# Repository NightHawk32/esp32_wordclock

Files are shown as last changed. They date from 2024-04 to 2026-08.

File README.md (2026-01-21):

# ESP32 WordClock - WiFi Setup Guide

This WordClock project is built around the **Ikea Sannahed 35x35cm picture frame**, transforming it into an elegant word-based time display with integrated sensors and web control.

## 📶 WiFi Setup

The WordClock features an automatic WiFi configuration system with two modes of operation:

### Initial Setup (Access Point Mode)

When the WordClock is powered on for the first time or cannot connect to a saved WiFi network, it automatically enters **Access Point (AP) Mode**:

1. **Connect to the WordClock's WiFi network:**
   - Network Name (SSID): `WordClock-Setup`
   - Password: `wordclock123`

2. **Access the configuration interface:**
   - Open your web browser and navigate to: `http://192.168.4.1`
   - You should see a yellow banner indicating "Access Point Mode"

3. **Configure your WiFi:**
   - Enter your home WiFi network name (SSID)
   - Enter your WiFi password
   - Click "Connect to WiFi"
   - The WordClock will save the settings and restart

4. **Reconnect to your home network:**
   - After restart, the WordClock will connect to your home WiFi
   - You can now disconnect from the `WordClock-Setup` network and reconnect to your home WiFi

### Normal Operation (Station Mode)

Once configured, the WordClock connects to your home WiFi network automatically. You can access the web interface in two ways:

#### Option 1: Using mDNS hostname (Recommended)
```
http://wordclock.local
```
This works on most devices without needing to know the IP address. The mDNS (Multicast DNS) service makes the WordClock discoverable on your local network.

> **Note:** mDNS may not work on all Android devices or older Windows versions. If `wordclock.local` doesn't work, use the IP address method below.

#### Option 2: Using IP Address
1. Check your router's DHCP client list to find the WordClock's IP address
2. Alternatively, connect via serial monitor (115200 baud) to see the IP address printed during startup
3. Navigate to: `http://[IP_ADDRESS]` (e.g., `http://192.168.1.100`)

## 🌐 Web Interface Features

Once connected, the web interface allows you to:

- **Display Mode:** Switch between word clock and digital clock modes
- **LED Color Control:** Adjust RGBW color values with preset options
- **Timezone Configuration:** Set your local timezone for accurate time display
- **Sensor Monitoring:** View real-time temperature, humidity, pressure, and brightness data
- **WiFi Reconfiguration:** Change WiFi settings if needed
- **Firmware Updates:** Update firmware over WiFi without USB cable (see OTA section below)

## 🔄 Over-The-Air (OTA) Firmware Updates

The WordClock supports wireless firmware updates, eliminating the need for USB cable after initial setup.

### Web-Based OTA Update (Recommended)

1. **Access the update page:**
   - Open http://wordclock.local
   - Click the "🔄 Go to Firmware Update Page" button
   - Or directly visit: http://wordclock.local/update

2. **Upload new firmware:**
   - Select the firmware file (`.bin`)
   - Click "Update"
   - Wait for the progress bar to complete
   - Device will automatically reboot

### PlatformIO Targets

You can also use PlatformIO to upload firmware over WiFi using the following target: OTA, which uses ArduinoOTA.
And uploads the firmware to the device over the network.
For the first upload you need to upload via the USB target to set up the WiFi connection.

### Windows Firewall / Defender Note

If OTA updates fail or timeout:
- **Windows Defender Firewall** may block OTA connections on port 3232
- **Solution:** Temporarily disable firewall or add exception for Python/PlatformIO
- **Alternative:** Use the web-based OTA method which uses standard HTTP port 80

## 🛠️ Hardware

This project is designed to fit perfectly in the **Ikea Sannahed 35x35cm picture frame**, providing a clean and modern aesthetic for your word clock display.

## 📝 Additional Configuration

After WiFi setup, you can configure:
- **Timezone:** Select from common timezones or use custom POSIX timezone strings
- **Display Colors:** Full RGBW control for customized appearance
- **Display Mode:** Choose between word-based or digital time display

The WordClock automatically syncs time via NTP (Network Time Protocol) when connected to WiFi, ensuring accurate timekeeping.

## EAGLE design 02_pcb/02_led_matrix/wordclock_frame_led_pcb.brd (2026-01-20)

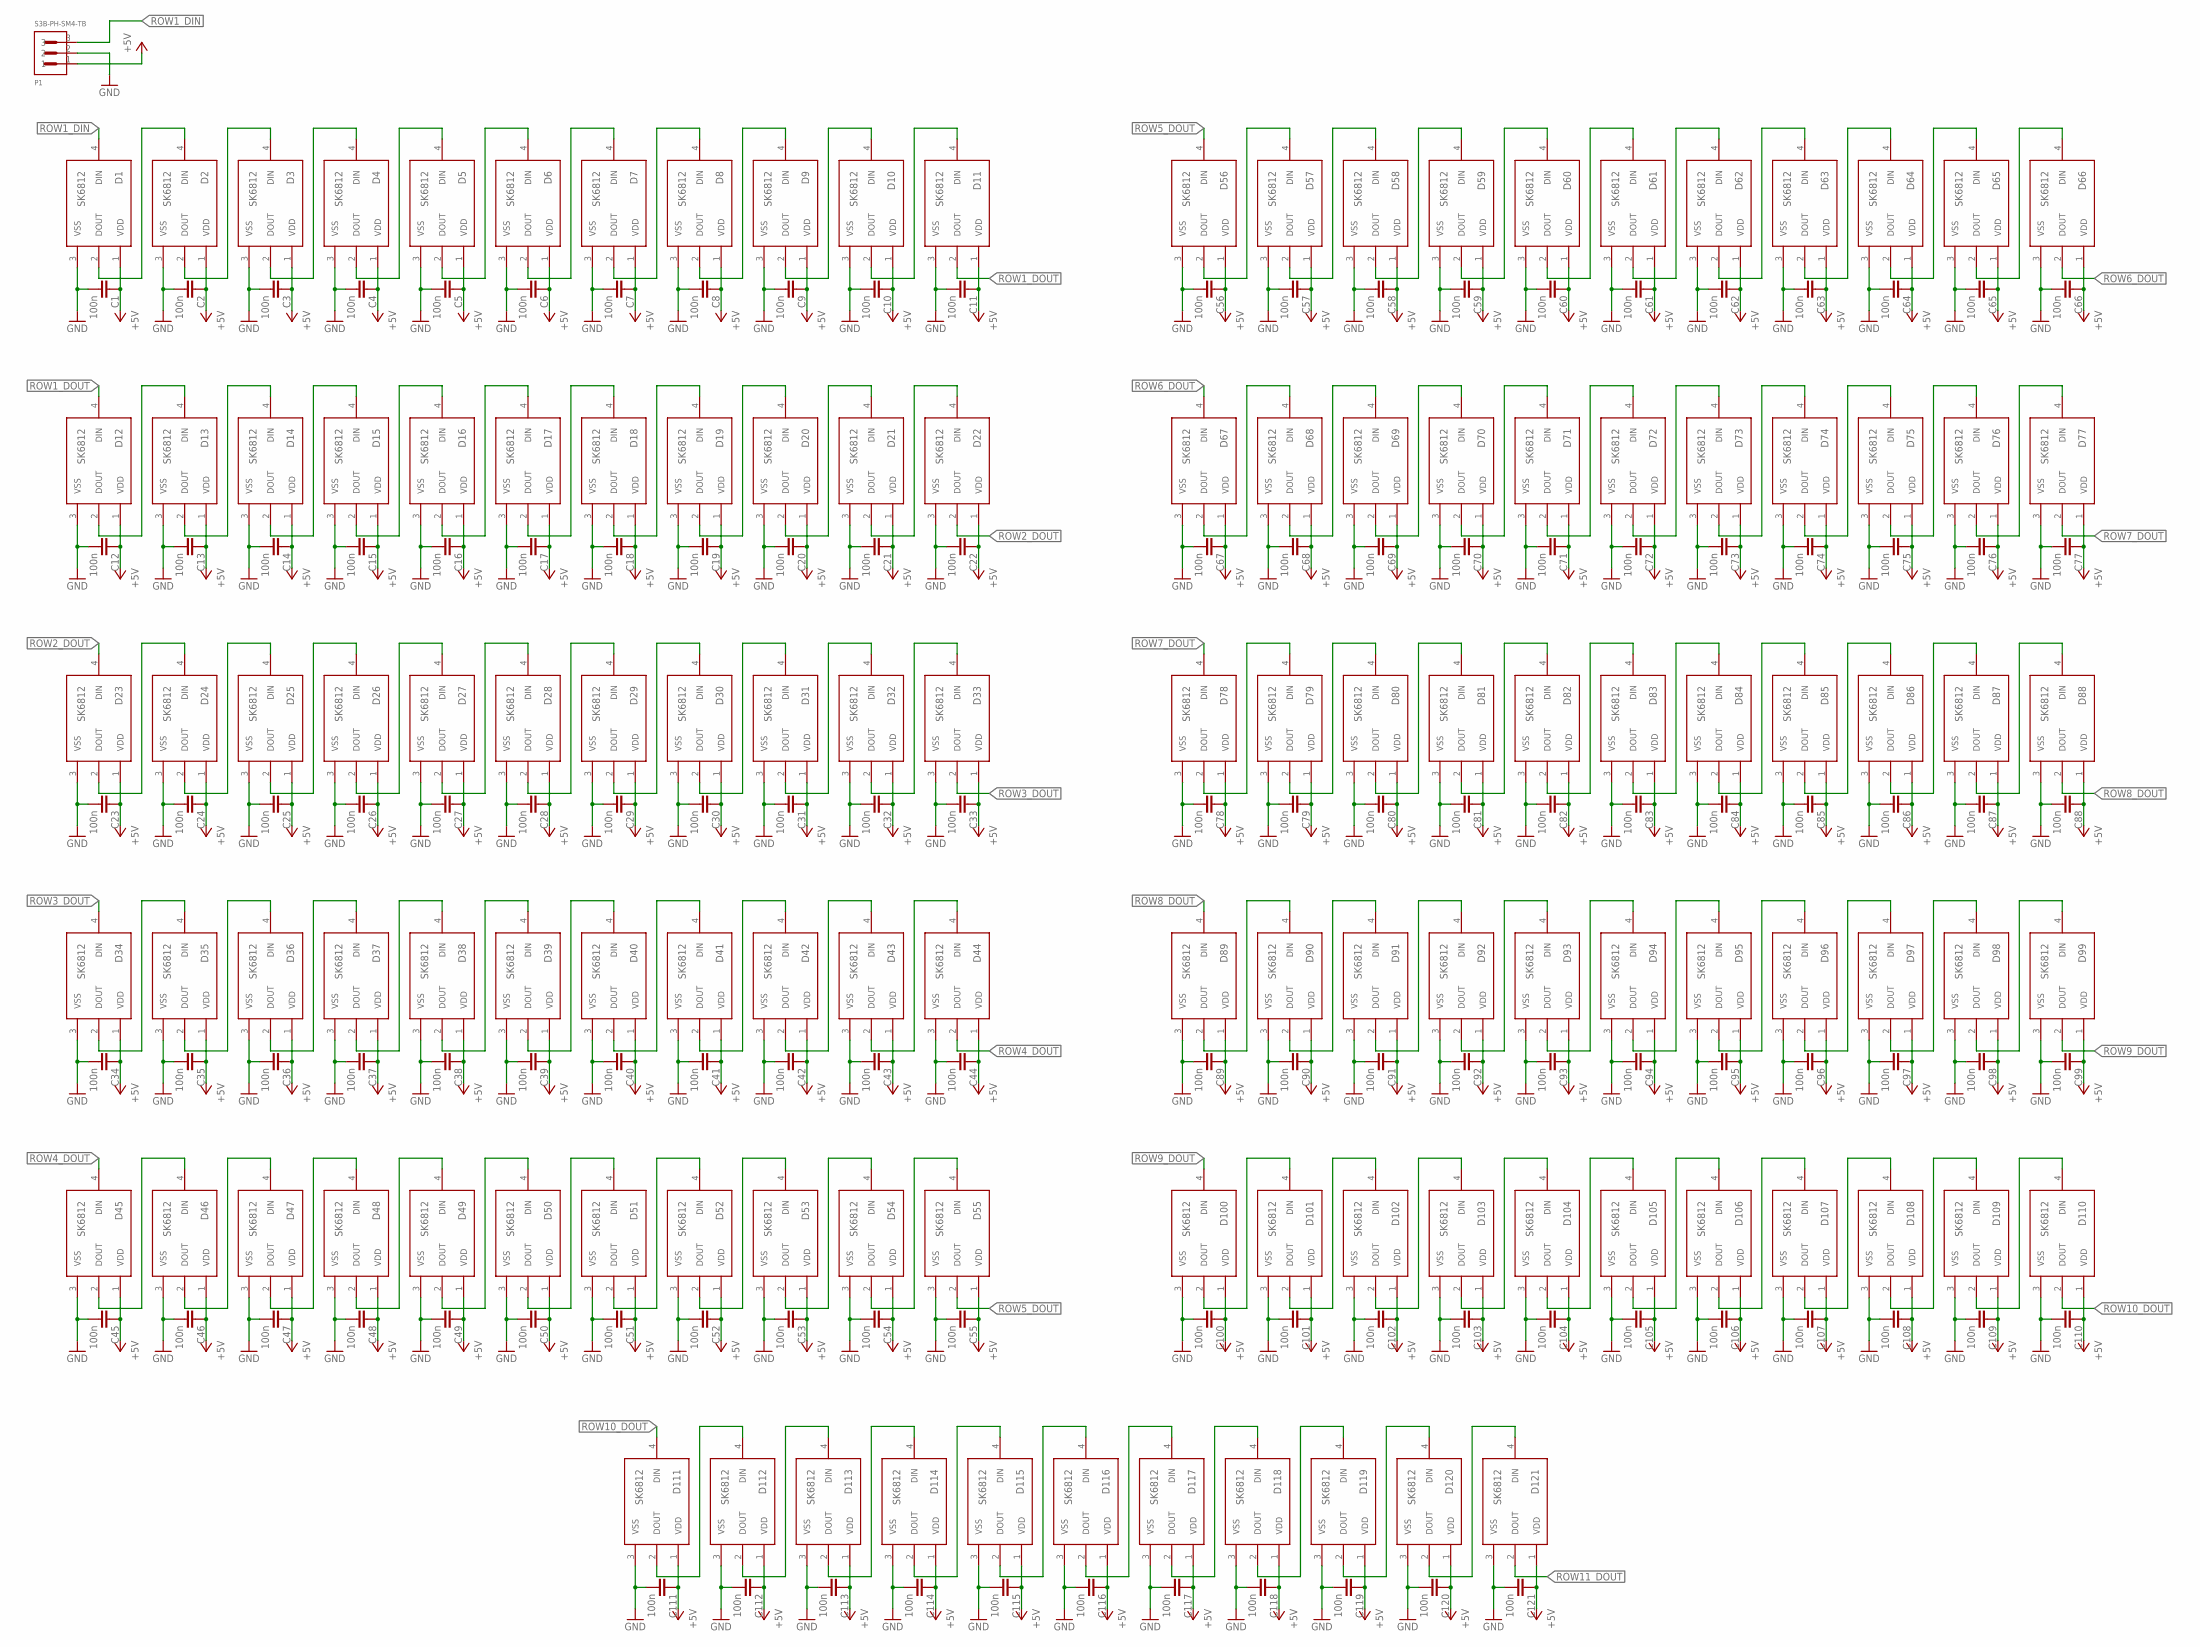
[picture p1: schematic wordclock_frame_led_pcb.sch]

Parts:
C1, C2, C3, C4, C5, C6, C7, C8, C9, C10, C11, C12, C13, C14, C15, C16, C17, C18, C19, C20, C21, C22, C23, C24, C25, C26, C27, C28, C29, C30, C31, C32, C33, C34, C35, C36, C37, C38, C39, C40, C41, C42, C43, C44, C45, C46, C47, C48, C49, C50, C51, C52, C53, C54, C55, C56, C57, C58, C59, C60, C61, C62, C63, C64, C65, C66, C67, C68, C69, C70, C71, C72, C73, C74, C75, C76, C77, C78, C79, C80, C81, C82, C83, C84, C85, C86, C87, C88, C89, C90, C91, C92, C93, C94, C95, C96, C97, C98, C99, C100, C101, C102, C103, C104, C105, C106, C107, C108, C109, C110, C111, C112, C113, C114, C115, C116, C117, C118, C119, C120, C121: 100n; C0603
D1, D2, D3, D4, D5, D6, D7, D8, D9, D10, D11, D12, D13, D14, D15, D16, D17, D18, D19, D20, D21, D22, D23, D24, D25, D26, D27, D28, D29, D30, D31, D32, D33, D34, D35, D36, D37, D38, D39, D40, D41, D42, D43, D44, D45, D46, D47, D48, D49, D50, D51, D52, D53, D54, D55, D56, D57, D58, D59, D60, D61, D62, D63, D64, D65, D66, D67, D68, D69, D70, D71, D72, D73, D74, D75, D76, D77, D78, D79, D80, D81, D82, D83, D84, D85, D86, D87, D88, D89, D90, D91, D92, D93, D94, D95, D96, D97, D98, D99, D100, D101, D102, D103, D104, D105, D106, D107, D108, D109, D110, D111, D112, D113, D114, D115, D116, D117, D118, D119, D120, D121: SK6812; LED_SK6812
P1: S3B-PH-SM4-TB; JST_S3B-PH-SM4-TB

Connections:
GND: C1.2, C2.2, C3.2, C4.2, C5.2, C6.2, C7.2, C8.2, C9.2, C10.2, C11.2, C12.2, C13.2, C14.2, C15.2, C16.2, C17.2, C18.2, C19.2, C20.2, C21.2, C22.2, C23.2, C24.2, C25.2, C26.2, C27.2, C28.2, C29.2, C30.2, C31.2, C32.2, C33.2, C34.2, C35.2, C36.2, C37.2, C38.2, C39.2, C40.2, C41.2, C42.2, C43.2, C44.2, C45.2, C46.2, C47.2, C48.2, C49.2, C50.2, C51.2, C52.2, C53.2, C54.2, C55.2, C56.2, C57.2, C58.2, C59.2, C60.2, C61.2, C62.2, C63.2, C64.2, C65.2, C66.2, C67.2, C68.2, C69.2, C70.2, C71.2, C72.2, C73.2, C74.2, C75.2, C76.2, C77.2, C78.2, C79.2, C80.2, C81.2, C82.2, C83.2, C84.2, C85.2, C86.2, C87.2, C88.2, C89.2, C90.2, C91.2, C92.2, C93.2, C94.2, C95.2, C96.2, C97.2, C98.2, C99.2, C100.2, C101.2, C102.2, C103.2, C104.2, C105.2, C106.2, C107.2, C108.2, C109.2, C110.2, C111.2, C112.2, C113.2, C114.2, C115.2, C116.2, C117.2, C118.2, C119.2, C120.2, C121.2, D1.3 (VSS), D2.3 (VSS), D3.3 (VSS), D4.3 (VSS), D5.3 (VSS), D6.3 (VSS), D7.3 (VSS), D8.3 (VSS), D9.3 (VSS), D10.3 (VSS), D11.3 (VSS), D12.3 (VSS), D13.3 (VSS), D14.3 (VSS), D15.3 (VSS), D16.3 (VSS), D17.3 (VSS), D18.3 (VSS), D19.3 (VSS), D20.3 (VSS), D21.3 (VSS), D22.3 (VSS), D23.3 (VSS), D24.3 (VSS), D25.3 (VSS), D26.3 (VSS), D27.3 (VSS), D28.3 (VSS), D29.3 (VSS), D30.3 (VSS), D31.3 (VSS), D32.3 (VSS), D33.3 (VSS), D34.3 (VSS), D35.3 (VSS), D36.3 (VSS), D37.3 (VSS), D38.3 (VSS), D39.3 (VSS), D40.3 (VSS), D41.3 (VSS), D42.3 (VSS), D43.3 (VSS), D44.3 (VSS), D45.3 (VSS), D46.3 (VSS), D47.3 (VSS), D48.3 (VSS), D49.3 (VSS), D50.3 (VSS), D51.3 (VSS), D52.3 (VSS), D53.3 (VSS), D54.3 (VSS), D55.3 (VSS), D56.3 (VSS), D57.3 (VSS), D58.3 (VSS), D59.3 (VSS), D60.3 (VSS), D61.3 (VSS), D62.3 (VSS), D63.3 (VSS), D64.3 (VSS), D65.3 (VSS), D66.3 (VSS), D67.3 (VSS), D68.3 (VSS), D69.3 (VSS), D70.3 (VSS), D71.3 (VSS), D72.3 (VSS), D73.3 (VSS), D74.3 (VSS), D75.3 (VSS), D76.3 (VSS), D77.3 (VSS), D78.3 (VSS), D79.3 (VSS), D80.3 (VSS), D81.3 (VSS), D82.3 (VSS), D83.3 (VSS), D84.3 (VSS), D85.3 (VSS), D86.3 (VSS), D87.3 (VSS), D88.3 (VSS), D89.3 (VSS), D90.3 (VSS), D91.3 (VSS), D92.3 (VSS), D93.3 (VSS), D94.3 (VSS), D95.3 (VSS), D96.3 (VSS), D97.3 (VSS), D98.3 (VSS), D99.3 (VSS), D100.3 (VSS), D101.3 (VSS), D102.3 (VSS), D103.3 (VSS), D104.3 (VSS), D105.3 (VSS), D106.3 (VSS), D107.3 (VSS), D108.3 (VSS), D109.3 (VSS), D110.3 (VSS), D111.3 (VSS), D112.3 (VSS), D113.3 (VSS), D114.3 (VSS), D115.3 (VSS), D116.3 (VSS), D117.3 (VSS), D118.3 (VSS), D119.3 (VSS), D120.3 (VSS), D121.3 (VSS), P1.2
unnamed: D1.2 (DOUT), D2.4 (DIN)
unnamed: D2.2 (DOUT), D3.4 (DIN)
unnamed: D3.2 (DOUT), D4.4 (DIN)
unnamed: D4.2 (DOUT), D5.4 (DIN)
unnamed: D5.2 (DOUT), D6.4 (DIN)
unnamed: D6.2 (DOUT), D7.4 (DIN)
unnamed: D7.2 (DOUT), D8.4 (DIN)
unnamed: D8.2 (DOUT), D9.4 (DIN)
unnamed: D9.2 (DOUT), D10.4 (DIN)
unnamed: D10.2 (DOUT), D11.4 (DIN)
unnamed: D12.2 (DOUT), D13.4 (DIN)
unnamed: D13.2 (DOUT), D14.4 (DIN)
unnamed: D14.2 (DOUT), D15.4 (DIN)
unnamed: D15.2 (DOUT), D16.4 (DIN)
unnamed: D16.2 (DOUT), D17.4 (DIN)
unnamed: D17.2 (DOUT), D18.4 (DIN)
unnamed: D18.2 (DOUT), D19.4 (DIN)
unnamed: D19.2 (DOUT), D20.4 (DIN)
unnamed: D20.2 (DOUT), D21.4 (DIN)
unnamed: D21.2 (DOUT), D22.4 (DIN)
unnamed: D23.2 (DOUT), D24.4 (DIN)
unnamed: D24.2 (DOUT), D25.4 (DIN)
unnamed: D25.2 (DOUT), D26.4 (DIN)
unnamed: D26.2 (DOUT), D27.4 (DIN)
unnamed: D27.2 (DOUT), D28.4 (DIN)
unnamed: D28.2 (DOUT), D29.4 (DIN)
unnamed: D29.2 (DOUT), D30.4 (DIN)
unnamed: D30.2 (DOUT), D31.4 (DIN)
unnamed: D31.2 (DOUT), D32.4 (DIN)
unnamed: D32.2 (DOUT), D33.4 (DIN)
unnamed: D34.2 (DOUT), D35.4 (DIN)
unnamed: D35.2 (DOUT), D36.4 (DIN)
unnamed: D36.2 (DOUT), D37.4 (DIN)
unnamed: D37.2 (DOUT), D38.4 (DIN)
unnamed: D38.2 (DOUT), D39.4 (DIN)
unnamed: D39.2 (DOUT), D40.4 (DIN)
unnamed: D40.2 (DOUT), D41.4 (DIN)
unnamed: D41.2 (DOUT), D42.4 (DIN)
unnamed: D42.2 (DOUT), D43.4 (DIN)
unnamed: D43.2 (DOUT), D44.4 (DIN)
unnamed: D45.2 (DOUT), D46.4 (DIN)
unnamed: D46.2 (DOUT), D47.4 (DIN)
unnamed: D47.2 (DOUT), D48.4 (DIN)
unnamed: D48.2 (DOUT), D49.4 (DIN)
unnamed: D49.2 (DOUT), D50.4 (DIN)
unnamed: D50.2 (DOUT), D51.4 (DIN)
unnamed: D51.2 (DOUT), D52.4 (DIN)
unnamed: D52.2 (DOUT), D53.4 (DIN)
unnamed: D53.2 (DOUT), D54.4 (DIN)
unnamed: D54.2 (DOUT), D55.4 (DIN)
unnamed: D56.2 (DOUT), D57.4 (DIN)
unnamed: D57.2 (DOUT), D58.4 (DIN)
unnamed: D58.2 (DOUT), D59.4 (DIN)
unnamed: D59.2 (DOUT), D60.4 (DIN)
unnamed: D60.2 (DOUT), D61.4 (DIN)
unnamed: D61.2 (DOUT), D62.4 (DIN)
unnamed: D62.2 (DOUT), D63.4 (DIN)
unnamed: D63.2 (DOUT), D64.4 (DIN)
unnamed: D64.2 (DOUT), D65.4 (DIN)
unnamed: D65.2 (DOUT), D66.4 (DIN)
unnamed: D67.2 (DOUT), D68.4 (DIN)
unnamed: D68.2 (DOUT), D69.4 (DIN)
unnamed: D69.2 (DOUT), D70.4 (DIN)
unnamed: D70.2 (DOUT), D71.4 (DIN)
unnamed: D71.2 (DOUT), D72.4 (DIN)
unnamed: D72.2 (DOUT), D73.4 (DIN)
unnamed: D73.2 (DOUT), D74.4 (DIN)
unnamed: D74.2 (DOUT), D75.4 (DIN)
unnamed: D75.2 (DOUT), D76.4 (DIN)
unnamed: D76.2 (DOUT), D77.4 (DIN)
unnamed: D78.2 (DOUT), D79.4 (DIN)
unnamed: D79.2 (DOUT), D80.4 (DIN)
unnamed: D80.2 (DOUT), D81.4 (DIN)
unnamed: D81.2 (DOUT), D82.4 (DIN)
unnamed: D82.2 (DOUT), D83.4 (DIN)
unnamed: D83.2 (DOUT), D84.4 (DIN)
unnamed: D84.2 (DOUT), D85.4 (DIN)
unnamed: D85.2 (DOUT), D86.4 (DIN)
unnamed: D86.2 (DOUT), D87.4 (DIN)
unnamed: D87.2 (DOUT), D88.4 (DIN)
unnamed: D89.2 (DOUT), D90.4 (DIN)
unnamed: D90.2 (DOUT), D91.4 (DIN)
unnamed: D91.2 (DOUT), D92.4 (DIN)
unnamed: D92.2 (DOUT), D93.4 (DIN)
unnamed: D93.2 (DOUT), D94.4 (DIN)
unnamed: D94.2 (DOUT), D95.4 (DIN)
unnamed: D95.2 (DOUT), D96.4 (DIN)
unnamed: D96.2 (DOUT), D97.4 (DIN)
unnamed: D97.2 (DOUT), D98.4 (DIN)
unnamed: D98.2 (DOUT), D99.4 (DIN)
unnamed: D100.2 (DOUT), D101.4 (DIN)
unnamed: D101.2 (DOUT), D102.4 (DIN)
unnamed: D102.2 (DOUT), D103.4 (DIN)
unnamed: D103.2 (DOUT), D104.4 (DIN)
unnamed: D104.2 (DOUT), D105.4 (DIN)
unnamed: D105.2 (DOUT), D106.4 (DIN)
unnamed: D106.2 (DOUT), D107.4 (DIN)
unnamed: D107.2 (DOUT), D108.4 (DIN)
unnamed: D108.2 (DOUT), D109.4 (DIN)
unnamed: D109.2 (DOUT), D110.4 (DIN)
unnamed: D111.2 (DOUT), D112.4 (DIN)
unnamed: D112.2 (DOUT), D113.4 (DIN)
unnamed: D113.2 (DOUT), D114.4 (DIN)
unnamed: D114.2 (DOUT), D115.4 (DIN)
unnamed: D115.2 (DOUT), D116.4 (DIN)
unnamed: D116.2 (DOUT), D117.4 (DIN)
unnamed: D117.2 (DOUT), D118.4 (DIN)
unnamed: D118.2 (DOUT), D119.4 (DIN)
unnamed: D119.2 (DOUT), D120.4 (DIN)
unnamed: D120.2 (DOUT), D121.4 (DIN)
ROW1_DIN: D1.4 (DIN), P1.3
ROW1_DOUT: D11.2 (DOUT), D12.4 (DIN)
ROW2_DOUT: D22.2 (DOUT), D23.4 (DIN)
ROW3_DOUT: D33.2 (DOUT), D34.4 (DIN)
ROW4_DOUT: D44.2 (DOUT), D45.4 (DIN)
ROW5_DOUT: D55.2 (DOUT), D56.4 (DIN)
ROW6_DOUT: D66.2 (DOUT), D67.4 (DIN)
ROW7_DOUT: D77.2 (DOUT), D78.4 (DIN)
ROW8_DOUT: D88.2 (DOUT), D89.4 (DIN)
ROW9_DOUT: D99.2 (DOUT), D100.4 (DIN)
ROW10_DOUT: D110.2 (DOUT), D111.4 (DIN)
ROW11_DOUT: D121.2 (DOUT)
VCC: C1.1, C2.1, C3.1, C4.1, C5.1, C6.1, C7.1, C8.1, C9.1, C10.1, C11.1, C12.1, C13.1, C14.1, C15.1, C16.1, C17.1, C18.1, C19.1, C20.1, C21.1, C22.1, C23.1, C24.1, C25.1, C26.1, C27.1, C28.1, C29.1, C30.1, C31.1, C32.1, C33.1, C34.1, C35.1, C36.1, C37.1, C38.1, C39.1, C40.1, C41.1, C42.1, C43.1, C44.1, C45.1, C46.1, C47.1, C48.1, C49.1, C50.1, C51.1, C52.1, C53.1, C54.1, C55.1, C56.1, C57.1, C58.1, C59.1, C60.1, C61.1, C62.1, C63.1, C64.1, C65.1, C66.1, C67.1, C68.1, C69.1, C70.1, C71.1, C72.1, C73.1, C74.1, C75.1, C76.1, C77.1, C78.1, C79.1, C80.1, C81.1, C82.1, C83.1, C84.1, C85.1, C86.1, C87.1, C88.1, C89.1, C90.1, C91.1, C92.1, C93.1, C94.1, C95.1, C96.1, C97.1, C98.1, C99.1, C100.1, C101.1, C102.1, C103.1, C104.1, C105.1, C106.1, C107.1, C108.1, C109.1, C110.1, C111.1, C112.1, C113.1, C114.1, C115.1, C116.1, C117.1, C118.1, C119.1, C120.1, C121.1, D1.1 (VDD), D2.1 (VDD), D3.1 (VDD), D4.1 (VDD), D5.1 (VDD), D6.1 (VDD), D7.1 (VDD), D8.1 (VDD), D9.1 (VDD), D10.1 (VDD), D11.1 (VDD), D12.1 (VDD), D13.1 (VDD), D14.1 (VDD), D15.1 (VDD), D16.1 (VDD), D17.1 (VDD), D18.1 (VDD), D19.1 (VDD), D20.1 (VDD), D21.1 (VDD), D22.1 (VDD), D23.1 (VDD), D24.1 (VDD), D25.1 (VDD), D26.1 (VDD), D27.1 (VDD), D28.1 (VDD), D29.1 (VDD), D30.1 (VDD), D31.1 (VDD), D32.1 (VDD), D33.1 (VDD), D34.1 (VDD), D35.1 (VDD), D36.1 (VDD), D37.1 (VDD), D38.1 (VDD), D39.1 (VDD), D40.1 (VDD), D41.1 (VDD), D42.1 (VDD), D43.1 (VDD), D44.1 (VDD), D45.1 (VDD), D46.1 (VDD), D47.1 (VDD), D48.1 (VDD), D49.1 (VDD), D50.1 (VDD), D51.1 (VDD), D52.1 (VDD), D53.1 (VDD), D54.1 (VDD), D55.1 (VDD), D56.1 (VDD), D57.1 (VDD), D58.1 (VDD), D59.1 (VDD), D60.1 (VDD), D61.1 (VDD), D62.1 (VDD), D63.1 (VDD), D64.1 (VDD), D65.1 (VDD), D66.1 (VDD), D67.1 (VDD), D68.1 (VDD), D69.1 (VDD), D70.1 (VDD), D71.1 (VDD), D72.1 (VDD), D73.1 (VDD), D74.1 (VDD), D75.1 (VDD), D76.1 (VDD), D77.1 (VDD), D78.1 (VDD), D79.1 (VDD), D80.1 (VDD), D81.1 (VDD), D82.1 (VDD), D83.1 (VDD), D84.1 (VDD), D85.1 (VDD), D86.1 (VDD), D87.1 (VDD), D88.1 (VDD), D89.1 (VDD), D90.1 (VDD), D91.1 (VDD), D92.1 (VDD), D93.1 (VDD), D94.1 (VDD), D95.1 (VDD), D96.1 (VDD), D97.1 (VDD), D98.1 (VDD), D99.1 (VDD), D100.1 (VDD), D101.1 (VDD), D102.1 (VDD), D103.1 (VDD), D104.1 (VDD), D105.1 (VDD), D106.1 (VDD), D107.1 (VDD), D108.1 (VDD), D109.1 (VDD), D110.1 (VDD), D111.1 (VDD), D112.1 (VDD), D113.1 (VDD), D114.1 (VDD), D115.1 (VDD), D116.1 (VDD), D117.1 (VDD), D118.1 (VDD), D119.1 (VDD), D120.1 (VDD), D121.1 (VDD), P1.1

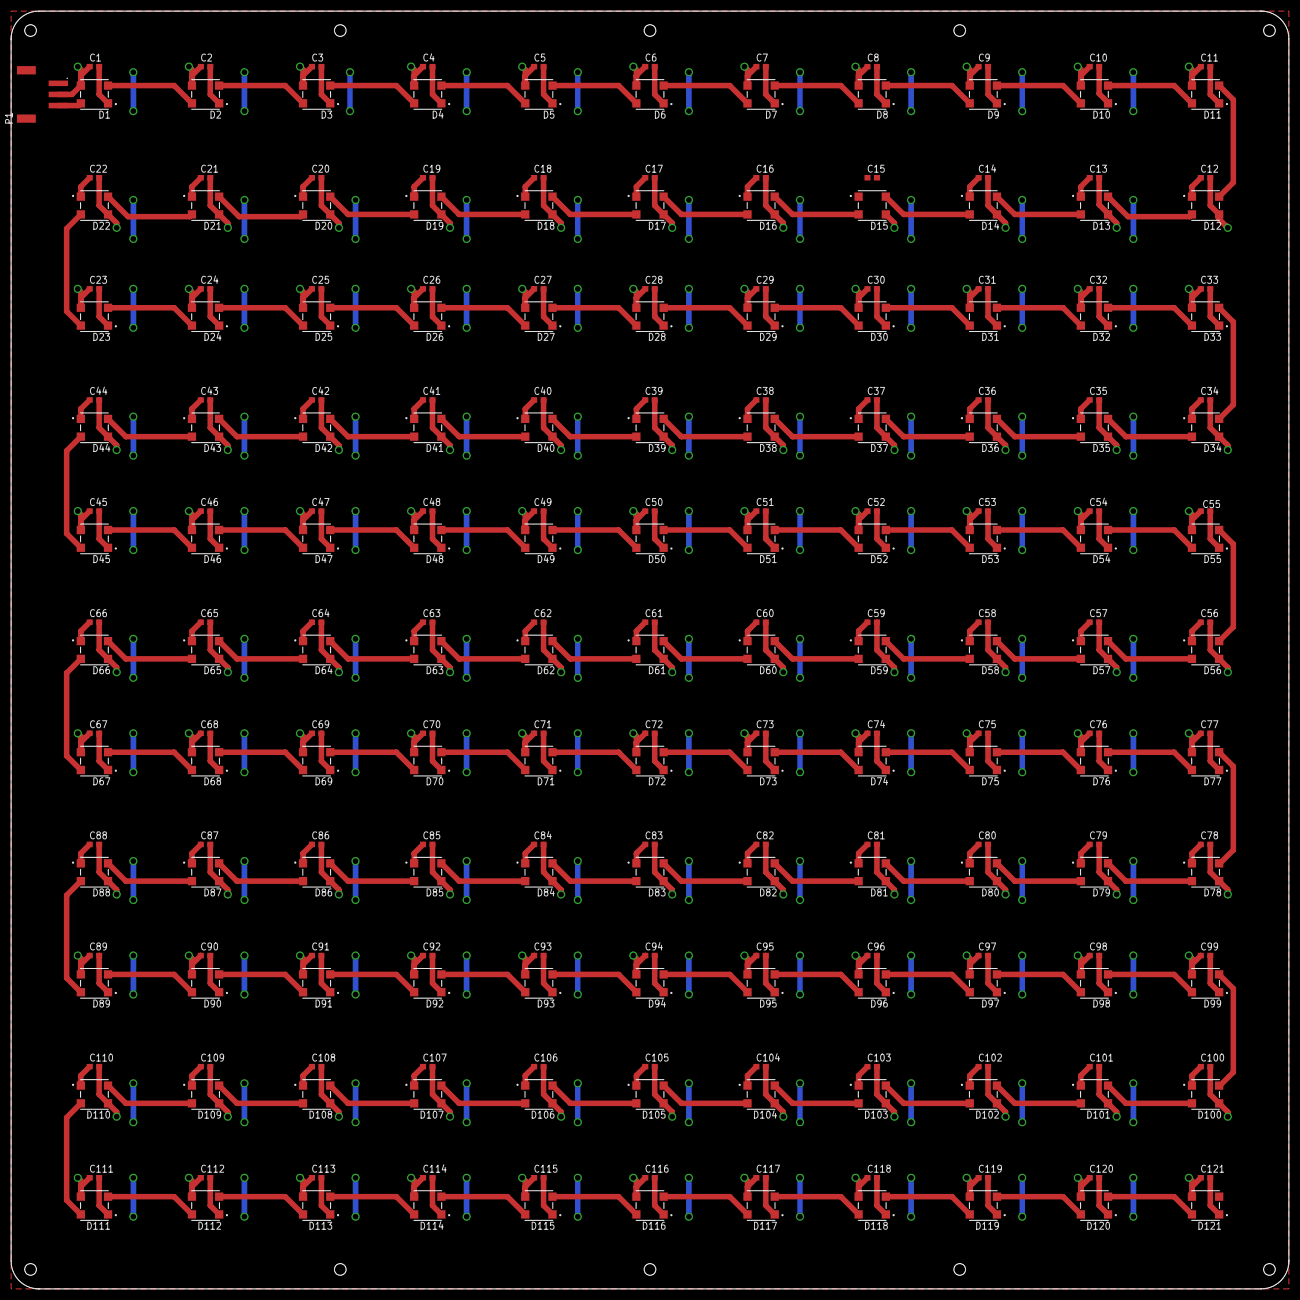
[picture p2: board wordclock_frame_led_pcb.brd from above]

Board: 2 copper layers, 230.0 x 230.0 mm, 243 parts (0 on the bottom side), 123 nets.

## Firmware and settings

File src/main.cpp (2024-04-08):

#include <Arduino.h>
#include <WiFi.h>
#include <time.h>
#include <Adafruit_NeoPixel.h>

#include "board.h"
#include "myWifi.h"

bool ledState = LED_OFF;
const long  gmtOffset_sec = 3600;
const int   daylightOffset_sec = 0;

#define LED_PIN     4

// How many NeoPixels are attached to the Arduino?
#define LED_COUNT  121

// NeoPixel brightness, 0 (min) to 255 (max)
#define BRIGHTNESS 255

// Declare our NeoPixel strip object:
Adafruit_NeoPixel strip(LED_COUNT, LED_PIN, NEO_GRBW + NEO_KHZ800);

int time_it_is[5] = {0, 1, 3, 4, 5}; // es ist

int time_minutes[12][12] = {
  { 99, 100, 101,  -1,  -1,  -1,  -1,  -1,  -1,  -1,  -1,  -1}, // uhr
  {  7,   8,   9,  10,  38,  39,  40,  41,  -1,  -1,  -1,  -1}, // fünf nach
  { 18,  19,  20,  21,  38,  39,  40,  41,  -1,  -1,  -1,  -1}, // zehn nach
  { 26,  27,  28,  29,  30,  31,  32,  38,  39,  40,  41,  -1}, // viertel nach
  { 11,  12,  13,  14,  15,  16,  17,  38,  39,  40,  41,  -1}, // zwanzig nach
  {  7,   8,   9,  10,  35,  36,  37,  44,  45,  46,  47,  -1}, // fünf vor halb
  { 44,  45,  46,  47,  -1,  -1,  -1,  -1,  -1,  -1,  -1,  -1}, // halb 
  {  7,   8,   9,  10,  38,  39,  40,  41,  44,  45,  46,  47}, // fünf nach halb
  { 11,  12,  13,  14,  15,  16,  17,  35,  36,  37,  -1,  -1}, // zwanzig vor
  { 26,  27,  28,  29,  30,  31,  32,  35,  36,  37,  -1,  -1}, // viertel vor
  { 18,  19,  20,  21,  35,  36,  37,  -1,  -1,  -1,  -1,  -1}, // zehn vor
  {  7,   8,   9,  10,  35,  36,  37,  -1,  -1,  -1,  -1,  -1}  // fünf vor
};

int time_hours[13][6] = {
  { 49,  50,  51,  52,  53,  -1}, // zwölf 
  { 60,  61,  62,  63,  -1,  -1}, // eins
  { 62,  63,  64,  65,  -1,  -1}, // zwei
  { 67,  68,  69,  70,  -1,  -1}, // drei
  { 77,  78,  79,  80,  -1,  -1}, // vier
  { 73,  74,  75,  76,  -1,  -1}, // fünf 
  {104, 105, 106, 107, 108,  -1}, // sechs
  { 55,  56,  57,  58,  59,  60}, // sieben 
  { 89,  90,  91,  92,  -1,  -1}, // acht
  { 81,  82,  83,  84,  -1,  -1}, // neun 
  { 93,  94,  95,  96,  -1,  -1}, // zehn
  { 85,  86,  87,  -1,  -1,  -1}, // elf
  { -1,  61,  62,  63,  -1,  -1}, // ein uhr
};

void setStime(uint hour, uint min)
{
  if(min >=30){
    hour+=1;
  }
  if(hour >= 12 ){
    hour -= 12;
  }  
  strip.fill(strip.Color(0, 0, 0, 0)); 

  for(int j=0; j<5;j++){
    strip.setPixelColor(time_it_is[j], strip.Color(255, 0, 0, 255));
  }

  uint minTemp = min / 5;
  for(int j=0; j<12;j++){
    strip.setPixelColor(time_minutes[minTemp][j], strip.Color(255, 0, 0, 255));
  }

  if(hour == 1 && minTemp == 0){
    for(int j=0; j<6;j++){
      strip.setPixelColor(time_hours[12][j], strip.Color(255, 0, 0, 255));
    }    
  }else{
    for(int j=0; j<6;j++){
      strip.setPixelColor(time_hours[hour][j], strip.Color(255, 0, 0, 255));
    }
  }  
  strip.show();
}

void printLocalTime(){
  struct tm timeinfo;
  if(!getLocalTime(&timeinfo)){
    Serial.println("Failed to obtain time");
    return;
  }
  Serial.println(&timeinfo, "%A, %B %d %Y %H:%M:%S");
}

void setTimezone(String timezone){
  Serial.printf("  Setting Timezone to %s\n",timezone.c_str());
  setenv("TZ",timezone.c_str(),1);  //  Now adjust the TZ.  Clock settings are adjusted to show the new local time
  tzset();
}

void setTime(int yr, int month, int mday, int hr, int minute, int sec, int isDst){
  struct tm tm;

  tm.tm_year = yr - 1900;   // Set date
  tm.tm_mon = month-1;
  tm.tm_mday = mday;
  tm.tm_hour = hr;      // Set time
  tm.tm_min = minute;
  tm.tm_sec = sec;
  tm.tm_isdst = isDst;  // 1 or 0
  time_t t = mktime(&tm);
  Serial.printf("Setting time: %s", asctime(&tm));
  struct timeval now = { .tv_sec = t };
  settimeofday(&now, NULL);
}

void initTime(String timezone){
  struct tm timeinfo;

  Serial.println("Setting up time");
  configTime(0, 0, "pool.ntp.org");    // First connect to NTP server, with 0 TZ offset
  if(!getLocalTime(&timeinfo)){
    Serial.println("  Failed to obtain time");
    return;
  }
  Serial.println("  Got the time from NTP");
  // Now we can set the real timezone
  setTimezone(timezone);
}

void scanNetworks() {
  Serial.println("Scan start");

  // WiFi.scanNetworks will return the number of networks found.
  int n = WiFi.scanNetworks();
  Serial.println("Scan done");
  if (n == 0) {
      Serial.println("no networks found");
  } else {
      Serial.print(n);
      Serial.println(" networks found");
      Serial.println("Nr | SSID                             | RSSI | CH | Encryption");
      for (int i = 0; i < n; ++i) {
          // Print SSID and RSSI for each network found
          Serial.printf("%2d",i + 1);
          Serial.print(" | ");
          Serial.printf("%-32.32s", WiFi.SSID(i).c_str());
          Serial.print(" | ");
          Serial.printf("%4ld", WiFi.RSSI(i));
          Serial.print(" | ");
          Serial.printf("%2ld", WiFi.channel(i));
          Serial.print(" | ");
          switch (WiFi.encryptionType(i))
          {
          case WIFI_AUTH_OPEN:
              Serial.print("open");
              break;
          case WIFI_AUTH_WEP:
              Serial.print("WEP");
              break;
          case WIFI_AUTH_WPA_PSK:
              Serial.print("WPA");
              break;
          case WIFI_AUTH_WPA2_PSK:
              Serial.print("WPA2");
              break;
          case WIFI_AUTH_WPA_WPA2_PSK:
              Serial.print("WPA+WPA2");
              break;
          case WIFI_AUTH_WPA2_ENTERPRISE:
              Serial.print("WPA2-EAP");
              break;
          case WIFI_AUTH_WPA3_PSK:
              Serial.print("WPA3");
              break;
          case WIFI_AUTH_WPA2_WPA3_PSK:
              Serial.print("WPA2+WPA3");
              break;
          case WIFI_AUTH_WAPI_PSK:
              Serial.print("WAPI");
              break;
          default:
              Serial.print("unknown");
          }
          Serial.println();
          delay(10);
      }
  }
  Serial.println("");

  // Delete the scan result to free memory for code below.
  WiFi.scanDelete();
}

void setup_wifi() {
  delay(10);
  WiFi.begin(MY_WIFI_SSID, MY_WIFI_PASSWORD);
  int counter = 0;
  while (WiFi.status() != WL_CONNECTED) {
    delay(500);
    if (++counter > 100) ESP.restart();
    Serial.print(".");
  }
  Serial.print("WiFi connected: ");
  Serial.println(MY_WIFI_SSID);
}

struct tm timeinfo;

void setup() {
	pinMode(PIN_LED, OUTPUT);
	digitalWrite(PIN_LED, LED_OFF);


	Serial.println("Starting ....");

	Serial.println("Setup done ....");

  strip.begin();           // INITIALIZE NeoPixel strip object (REQUIRED)
  strip.show();            // Turn OFF all pixels ASAP
  strip.setBrightness(BRIGHTNESS);

  configTime(gmtOffset_sec, daylightOffset_sec, NTP_SERVER);
  scanNetworks();
  setup_wifi();

  initTime("CET-1CEST,M3.5.0,M10.5.0/3");

}

long nextUpdate = 0;

void loop()
{	
  if(WiFi.status() != WL_CONNECTED){
    setup_wifi();
    digitalWrite(PIN_LED, LED_OFF);
  }else{
    digitalWrite(PIN_LED, LED_ON);
  }

  if(millis() > nextUpdate){
    
    if(!getLocalTime(&timeinfo)){
      Serial.println("Failed to obtain time");
      return;
    }
    Serial.println(&timeinfo, "%A, %B %d %Y %H:%M:%S");
    nextUpdate = millis() + (60-timeinfo.tm_sec)*1000;
    setStime(timeinfo.tm_hour, timeinfo.tm_min);
    //xSemaphoreGive(semDisplay);
  }

}

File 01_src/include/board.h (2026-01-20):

#ifndef BOARD_H_
#define BOARD_H_

#include <Tsl2561Util.h>

#define PIN_LED 5
#define LED_OFF true
#define LED_ON false

#define OUT_OFF false
#define OUT_ON false

#define LED_BUS_PIN 4

#define PIN_BOOT 9

#define PIN_SDA 1
#define PIN_SCL 0

#define OUT_CH1 7
#define OUT_CH2 6

#define TSL2561_ADDR Tsl2561::ADDR_FLOAT

#endif

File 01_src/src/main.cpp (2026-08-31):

#include <Arduino.h>
#include <WiFi.h>
#include <time.h>
#include <Wire.h>

#include "board.h"
#include "wifi_manager.h"
#include "time_utils.h"
#include "sensors.h"
#include "display.h"
#include "web_server.h"
#include "settings.h"
#include "ota_manager.h"

struct tm timeinfo;

// All schedules use unsigned millis() deltas so they survive the 49-day
// rollover - a clock is expected to run for months without a reboot.
static uint32_t nextDisplayUpdate = 0;
static uint32_t nextSensorUpdate = 0;
static uint32_t nextStatusLed = 0;
static bool otaStarted = false;
static bool timeWasValid = false;

static inline bool due(uint32_t deadline) {
  return (int32_t)(millis() - deadline) >= 0;
}

// Forward declarations
void updateSensorData(float temp, float hum, float press, float lux);
void forceDisplayRefresh();

// Status LED: solid = online, slow blink = reconnecting, fast blink = setup AP.
static void updateStatusLed() {
  if (!due(nextStatusLed)) return;

  if (isWifiConnected()) {
    digitalWrite(PIN_LED, LED_ON);
    nextStatusLed = millis() + 500;
    return;
  }

  static bool on = false;
  on = !on;
  digitalWrite(PIN_LED, on ? LED_ON : LED_OFF);
  nextStatusLed = millis() + (isAPMode() ? 150 : 600);
}

void setup() {
  Serial.begin(115200);
  Serial.println("Starting ....");

  pinMode(PIN_LED, OUTPUT);
  digitalWrite(PIN_LED, LED_OFF);

  Wire.begin(PIN_SDA, PIN_SCL);

  // Initialize settings (flash storage)
  initSettings();

  // Load and apply saved display settings
  DisplaySettings displaySettings = loadDisplaySettings();
  setLedColor(displaySettings.red, displaySettings.green, displaySettings.blue, displaySettings.white);
  setDisplayMode(displaySettings.mode);
  Serial.printf("Loaded settings - Mode: %d, RGBW: %d,%d,%d,%d\n",
                displaySettings.mode, displaySettings.red, displaySettings.green,
                displaySettings.blue, displaySettings.white);

  // Initialize display
  initDisplay();

  // Light every pixel so a dead LED can be spotted, then show the WiFi icon
  // while the connection comes up.
  ledSelfTest(5000);
  showWifi(strip.Color(0, 0, 0, 255));

  // Kick off the WiFi connection. This returns immediately - wifiLoop() drives
  // the retries, the AP fallback and the NTP sync from loop(), so boot is not
  // held up by an unreachable router.
  wifiInit();

  // Sensors
  printTSL();
  initBME688();

  // The web server (and with it the config portal) comes up right away, in
  // station mode or AP mode alike.
  initWebServer();
}

void loop()
{
  // Non-blocking WiFi state machine + captive portal DNS.
  wifiLoop();

  // ArduinoOTA can only be armed once we actually have an IP.
  if (isWifiConnected()) {
    if (!otaStarted) {
      initOTA();
      otaStarted = true;
    }
    handleOTA();
  }

  handleWebServer();
  updateStatusLed();

  // Log the first successful sync and force a redraw with the real time.
  if (!timeWasValid && isTimeValid()) {
    timeWasValid = true;
    Serial.println("Time synchronised");
    nextDisplayUpdate = millis();
  }

  // --- Display -------------------------------------------------------------
  // Driven by the RTC, not by the link state: once the time has been synced the
  // clock keeps showing it through a WiFi outage instead of falling back to a
  // placeholder.
  if (due(nextDisplayUpdate)) {
    if (isTimeValid() && getLocalTime(&timeinfo, 0)) {
      Serial.println(&timeinfo, "%A, %B %d %Y %H:%M:%S");
      updateDisplay(timeinfo.tm_hour, timeinfo.tm_min);
      // Re-align to the top of the next minute.
      nextDisplayUpdate = millis() + (60 - timeinfo.tm_sec) * 1000UL;
    } else {
      // No time yet: show 12:00 as a placeholder and check back shortly.
      updateDisplay(12, 0);
      nextDisplayUpdate = millis() + 5000;
    }
  }

  // --- Sensors -------------------------------------------------------------
  if (due(nextSensorUpdate)) {
    uint32_t milliLux = printTSL();
    float lux = milliLux / 1000.0f;

    updateBrightness(lux);
    printBME688();

    updateSensorData(getTemperature(), getHumidity(), getPressure(), lux);

    nextSensorUpdate = millis() + 5000;
  }

  // Yield to the WiFi/TCP tasks.
  delay(5);
}

// Force an immediate display refresh (called from the web interface).
void forceDisplayRefresh() {
  if (isTimeValid() && getLocalTime(&timeinfo, 0)) {
    updateDisplay(timeinfo.tm_hour, timeinfo.tm_min);
  } else {
    updateDisplay(12, 0);
  }
}

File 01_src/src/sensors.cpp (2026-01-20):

#include "sensors.h"
#include "board.h"

Tsl2561 Tsl(Wire);
Adafruit_BME680 bme;

// Cached sensor values
static float cachedTemperature = 0;
static float cachedHumidity = 0;
static float cachedPressure = 0;
static uint32_t cachedGasResistance = 0;

static char *format( const char *fmt, ... ) {
  static char buf[128];
  va_list arg;
  va_start(arg, fmt);
  vsnprintf(buf, sizeof(buf), fmt, arg);
  buf[sizeof(buf)-1] = '\0';
  va_end(arg);
  return buf;
}

uint32_t printTSL(){
  bool found = false;
  uint32_t milliLux = 0;

  if( Tsl.begin(TSL2561_ADDR) ) {
    found = true;
    Serial.println();

    uint16_t scaledFull = 0, scaledIr;
    uint32_t full, ir;
    uint8_t id;
    bool gain = 1;
    Tsl2561::exposure_t exposure = (Tsl2561::exposure_t)2;
    Tsl.on();

    Tsl.setSensitivity(gain, exposure);
    Tsl2561Util::waitNext(exposure);
    Tsl.id(id);
    Tsl.getSensitivity(gain, exposure);
    Tsl.fullLuminosity(scaledFull);
    Tsl.irLuminosity(scaledIr);

    Serial.print(format("Tsl2561 addr: 0x%02x, id: 0x%02x, sfull: %5u, sir: %5u, gain: %d, exp: %d",
      TSL2561_ADDR, id, scaledFull, scaledIr, gain, exposure));

    if( Tsl2561Util::normalizedLuminosity(gain, exposure, full = scaledFull, ir = scaledIr) ) {
      if( Tsl2561Util::milliLux(full, ir, milliLux, Tsl2561::packageCS(id)) ) {
        Serial.print(format(", full: %5lu, ir: %5lu, lux: %5lu.%03lu\n", (unsigned long)full, (unsigned long)ir, (unsigned long)milliLux/1000, (unsigned long)milliLux%1000));
      }
    }

    Tsl.off();
  }
  return milliLux;
}

void initBME688() {
  Serial.println("Initializing BME688 sensor...");
  
  if (!bme.begin(0x76)) {  // Try alternate address 0x76 (default is 0x77)
    Serial.println("Could not find a valid BME688 sensor, check wiring!");
    return;
  }
  
  // Set up oversampling and filter initialization
  bme.setTemperatureOversampling(BME680_OS_8X);
  bme.setHumidityOversampling(BME680_OS_2X);
  bme.setPressureOversampling(BME680_OS_4X);
  bme.setIIRFilterSize(BME680_FILTER_SIZE_3);
  bme.setGasHeater(320, 150); // 320°C for 150 ms
  
  Serial.println("BME688 sensor initialized successfully!");
}

void printBME688() {
  if (!bme.performReading()) {
    Serial.println("Failed to perform BME688 reading");
    return;
  }
  
  // Cache values
  cachedTemperature = bme.temperature;
  cachedHumidity = bme.humidity;
  cachedPressure = bme.pressure / 100.0;
  cachedGasResistance = bme.gas_resistance;
  
  Serial.println("\n=== BME688 Sensor Data ===");
  Serial.print("Temperature: ");
  Serial.print(cachedTemperature);
  Serial.println(" °C");
  
  Serial.print("Humidity: ");
  Serial.print(cachedHumidity);
  Serial.println(" %");
  
  Serial.print("Pressure: ");
  Serial.print(cachedPressure);
  Serial.println(" hPa");
  
  Serial.print("Gas Resistance: ");
  Serial.print(cachedGasResistance / 1000.0);
  Serial.println(" KOhms");
  
  Serial.print("Altitude: ");
  Serial.print(bme.readAltitude(1013.25)); // Sea level pressure
  Serial.println(" m");
  Serial.println("========================\n");
}

float getTemperature() {
  return cachedTemperature;
}

float getHumidity() {
  return cachedHumidity;
}

float getPressure() {
  return cachedPressure;
}

uint32_t getGasResistance() {
  return cachedGasResistance;
}

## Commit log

2026-01-20 added more resources and fixed small bug
    [wordclock_frame_led_pcb.brd, wordclock_frame_led_pcb.sch]
2026-01-20 added CAD data and BME688 driver
2026-01-23 fixed bug when showing "eins"
    [display.cpp, main.cpp]
2026-08-31 Add LED self-test function to display for diagnostics
2026-09-13 Fix hour calculation in setStime function to correctly handle 12-hour format
    [display.cpp]
